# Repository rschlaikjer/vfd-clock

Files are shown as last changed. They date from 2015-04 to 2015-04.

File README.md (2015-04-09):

# VFD Clock

### Bedside clock with extended info

I'm a sucker for [old display technologies](https://github.com/rschlaikjer/ntp-nixie),
so on my arduino binge I built a bedside clock capable of displaying generic
information, with long line scrolling and whatnot. The design is fully PoE, so
the finished clock just needs one cable.

**In this repo:**
- Arduino code for the clock logic, handles fetching data from the server and VFD control.
- Eagle schematics for the clock control PCB
- Housing DXF for laser cut housing. The design is intended to be cut on a 6.7mm material.
- Server code manages actual information fetching (checking my unread mail, getting the price of bitcoin)

## Partlist
- Atmega 328P (along with 16MHz crystal, 2x 22pf caps)
- Silvertel A9700 PoE module
- ENC28J60 ethernet PHY
- RB1-125BHQ1A RJ45 jack with magnetics
- LM1117 3.3V regulator (for ENC28J60)
- VFD with serial interface (Here I'm using a Noritake CU20045SCPB-T31A)

## Pretty pictures

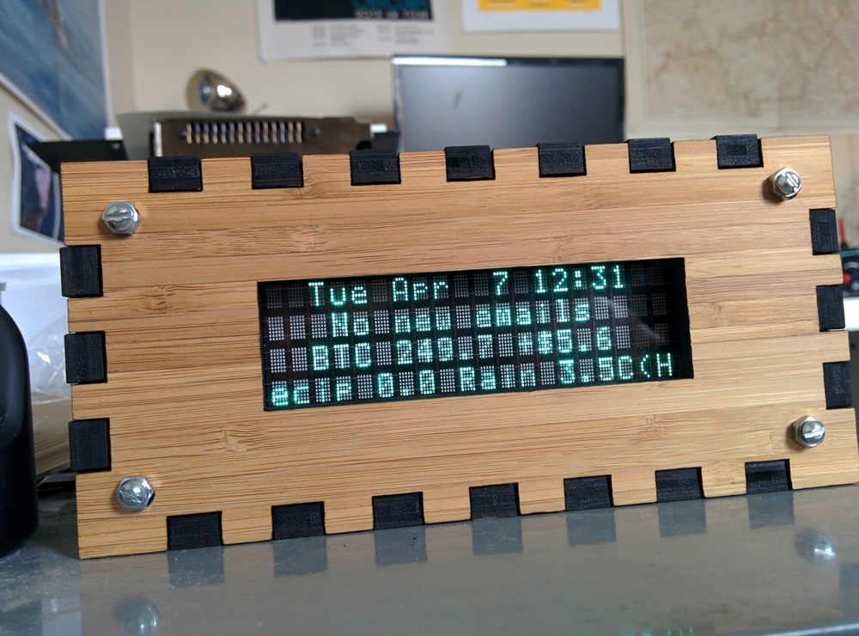
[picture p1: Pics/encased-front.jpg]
Front Front view

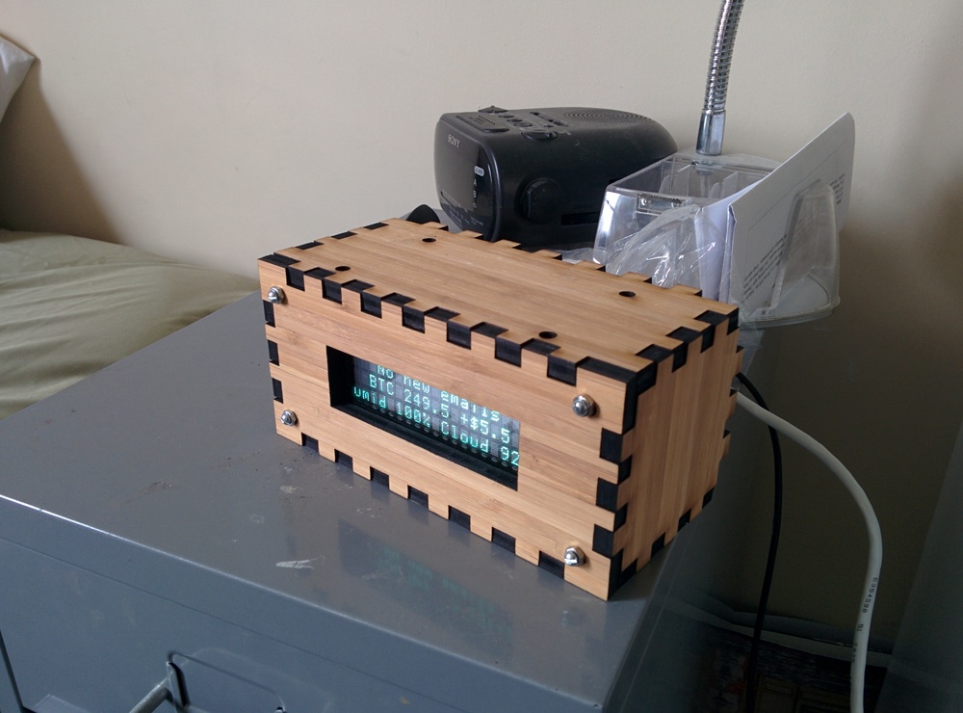
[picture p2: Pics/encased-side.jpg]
Side Side view

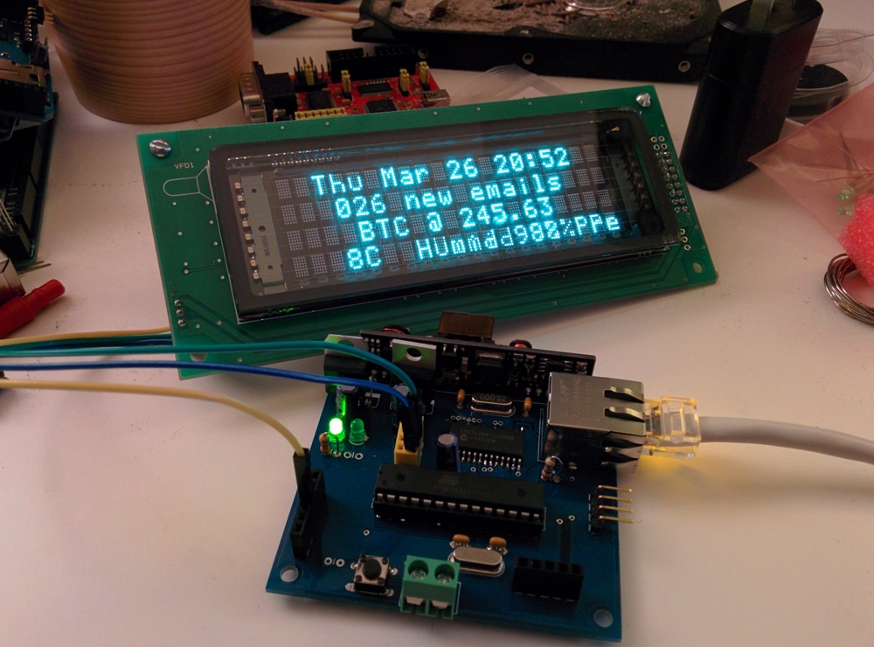
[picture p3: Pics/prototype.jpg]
Proto Initial testing


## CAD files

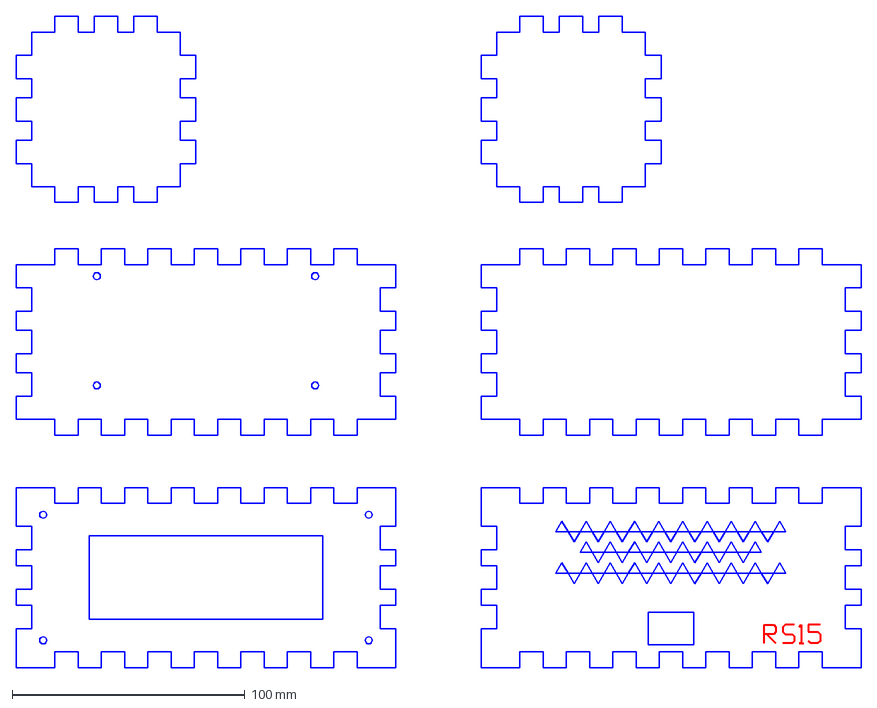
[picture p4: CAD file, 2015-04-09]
Housing/vfdclock.dxf
363.4 x 280.0 mm

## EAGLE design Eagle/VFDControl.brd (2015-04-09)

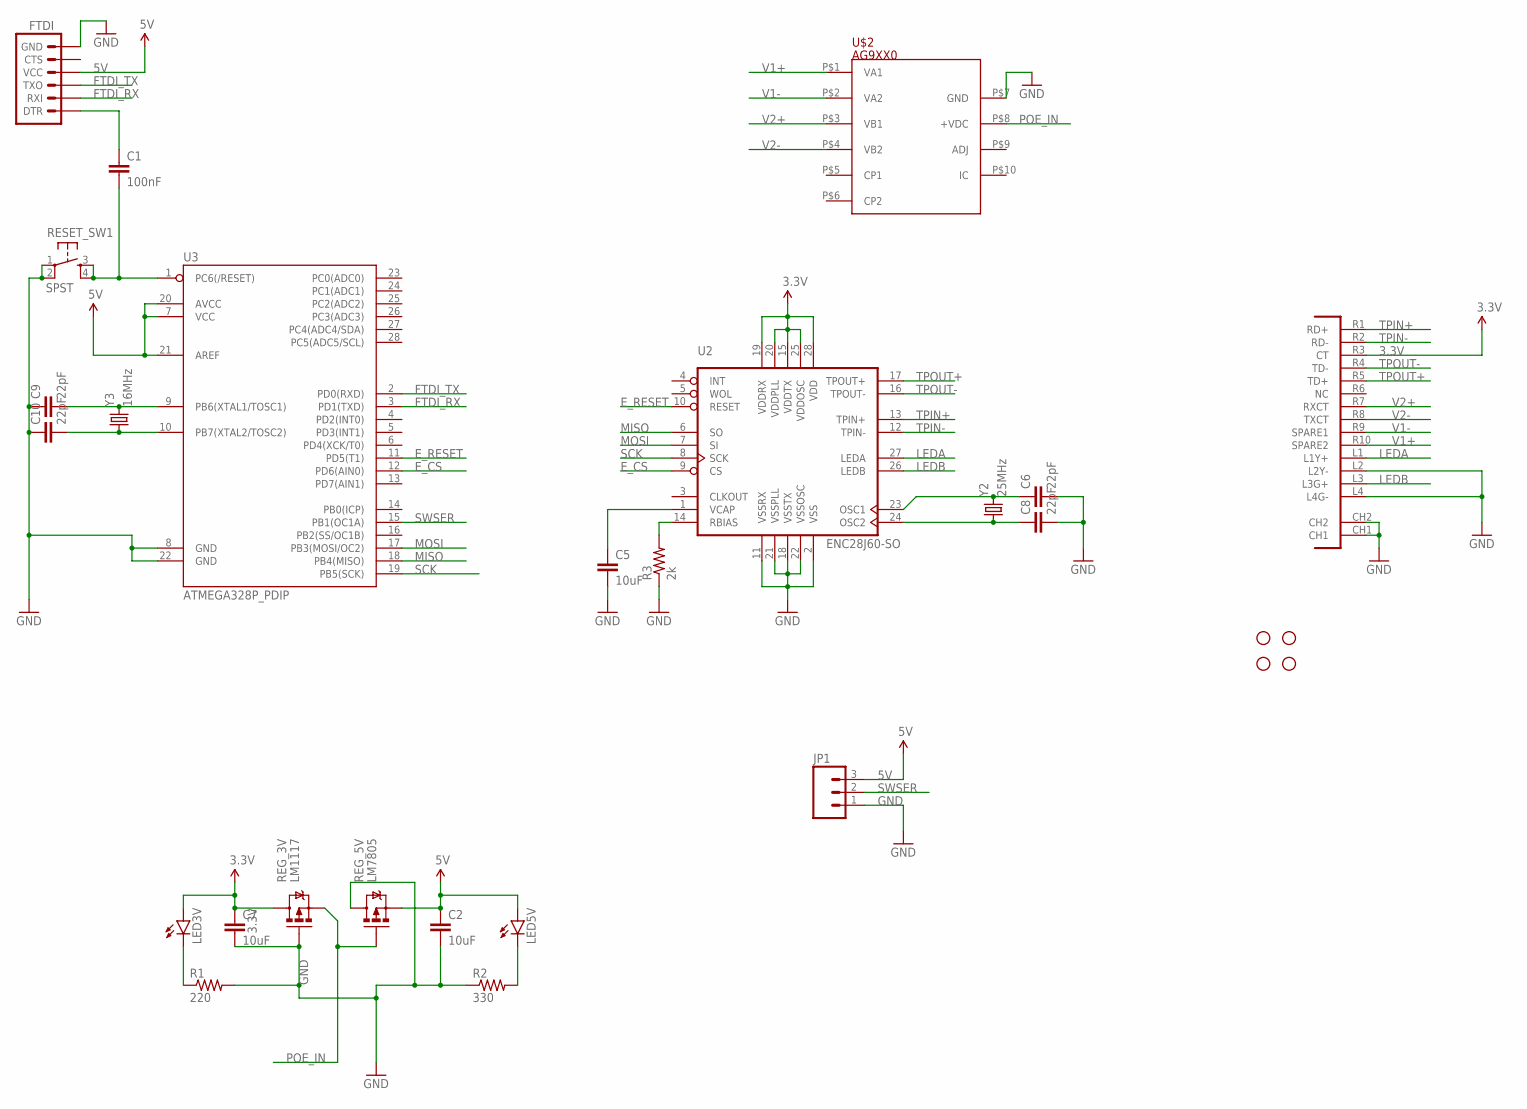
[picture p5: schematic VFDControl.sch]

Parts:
C1: 100nF; CAP-PTH-SMALL
C2, C5, C7: 10uF; CAP-PTH-SMALL
C6, C8, C9, C10: 22pF; CAP-PTH-SMALL
FTDI: ARDUINO_SERIAL_PROGRAMPTH; 1X06
JP1: M03PTH; 1X03
LED3V, LED5V: LED3MM
R1: 220; AXIAL-0.1
R2: 330; AXIAL-0.1
R3: 2k; AXIAL-0.1
REG_3V: LM1117; TO220V
REG_5V: LM7805; TO220V
RESET_SW1: SPST; TAC-SWITCH-PTH
STANDOFF1, STANDOFF2, STANDOFF3, STANDOFF4: STAND-OFF
U2: ENC28J60-SO; SO28W
U3: ATMEGA328P_PDIP; DIL28-3
U$2: AG9XX0; AG9000
U$3: POE-RJ45
Y2: 25MHz; HC49US
Y3: 16MHz; HC49US

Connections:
3.3V: C7.1, LED3V.A, REG_3V.2 (D), U2.15 (VDDTX), U2.19 (VDDRX), U2.20 (VDDPLL), U2.25 (VDDOSC), U2.28 (VDD), U$3.R3 (CT)
5V: C2.1, FTDI.4 (VCC), JP1.3, LED5V.A, REG_5V.3 (S), U3.7 (VCC), U3.20 (AVCC), U3.21 (AREF)
E_CS: U2.9 (CS), U3.12 (PD6(AIN0))
E_RESET: U2.10 (RESET), U3.11 (PD5(T1))
FTDI_RX: FTDI.2 (RXI), U3.3 (PD1(TXD))
FTDI_TX: FTDI.3 (TXO), U3.2 (PD0(RXD))
GND: C2.2, C5.2, C6.2, C7.2, C8.2, C9.1, C10.1, FTDI.6 (GND), JP1.1, R1.P$2 (2), R2.P$1 (1), R3.P$1 (1), REG_3V.1 (G), REG_5V.2 (D), RESET_SW1.1, RESET_SW1.2, U2.2 (VSS), U2.11 (VSSRX), U2.18 (VSSTX), U2.21 (VSSPLL), U2.22 (VSSOSC), U3.8 (GND), U3.22 (GND), U$2.P$7 (GND), U$3.CH1, U$3.CH2, U$3.L2 (L2Y-), U$3.L4 (L4G-)
LEDA: U2.27 (LEDA), U$3.L1 (L1Y+)
LEDB: U2.26 (LEDB), U$3.L3 (L3G+)
MISO: U2.6 (SO), U3.18 (PB4(MISO))
MOSI: U2.7 (SI), U3.17 (PB3(MOSI/OC2))
unnamed: LED3V.K (C), R1.P$1 (1)
unnamed: LED5V.K (C), R2.P$2 (2)
unnamed: R3.P$2 (2), U2.14 (RBIAS)
unnamed: C5.1, U2.1 (VCAP)
unnamed: C6.1, U2.23 (OSC1), Y2.2
unnamed: C8.1, U2.24 (OSC2), Y2.1
unnamed: C9.2, U3.9 (PB6(XTAL1/TOSC1)), Y3.2
unnamed: C10.2, U3.10 (PB7(XTAL2/TOSC2)), Y3.1
unnamed: C1.1, FTDI.1 (DTR)
POE_IN: REG_3V.3 (S), REG_5V.1 (G), U$2.P$8 (+VDC)
RESET: C1.2, RESET_SW1.3, RESET_SW1.4, U3.1 (PC6(/RESET))
SCK: U2.8 (SCK), U3.19 (PB5(SCK))
SWSER: JP1.2, U3.15 (PB1(OC1A))
TPIN+: U2.13 (TPIN+), U$3.R1 (RD+)
TPIN-: U2.12 (TPIN-), U$3.R2 (RD-)
TPOUT+: U2.17 (TPOUT+), U$3.R5 (TD+)
TPOUT-: U2.16 (TPOUT-), U$3.R4 (TD-)
V1+: U$2.P$1 (VA1), U$3.R10 (SPARE2)
V1-: U$2.P$2 (VA2), U$3.R9 (SPARE1)
V2+: U$2.P$3 (VB1), U$3.R7 (RXCT)
V2-: U$2.P$4 (VB2), U$3.R8 (TXCT)

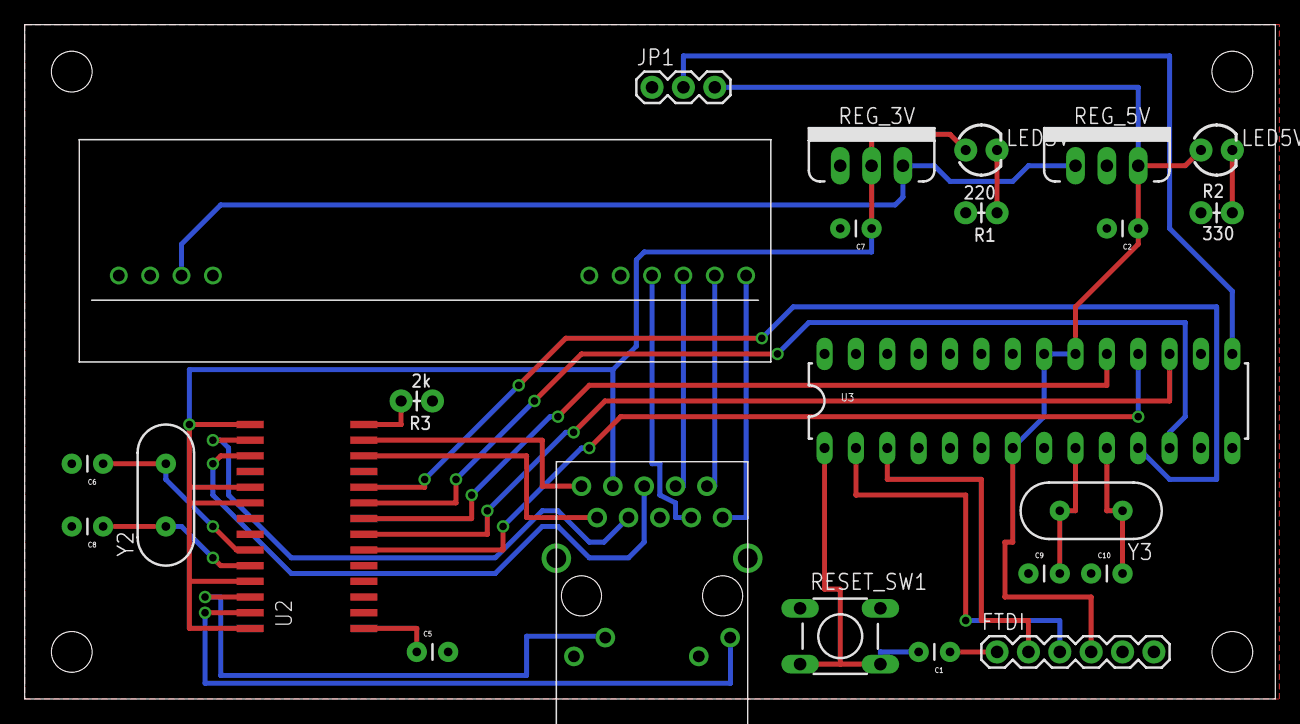
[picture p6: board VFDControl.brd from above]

Board: 2 copper layers, 101.3 x 54.6 mm, 28 parts (0 on the bottom side), 32 nets.

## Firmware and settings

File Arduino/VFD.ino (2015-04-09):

#include <SoftwareSerial.h>
#include <SPI.h>
#include <Wire.h>
#include <EtherCard.h>
#include <ArduinoJson.h>


// Ethernet
byte mac[] = {0xDE, 0xAD, 0xBE, 0xEF, 0xBA, 0xBE};
byte myip[] = { 192, 168, 0, 6 };
byte gwip[] = { 192, 168, 0, 1 };
byte Ethernet::buffer[512];
boolean OUTSTANDING_WWW_REQ = false;

// VFD
SoftwareSerial VFD(6,10); // RX, TX
#define VFD_LINES 4
#define VFD_COLS 20
#define VFD_COLMAX 64
char VFD_TEXT[VFD_LINES][VFD_COLMAX];
int VFD_SCROLL_INDEX[VFD_LINES];
int VFD_CUR_LINELEN[VFD_LINES];
short luminance = 0xFF;
short charset_control = 0x18;
#define VFD_TICK_MILLIS 125
#define DATA_CHECK_MILLIS 15000

// Function prototypes
void postTempData(short node_id, float temp, float pressure, float humidity);
void parseHTTPResponse();
void http_handle_resp(byte status, word off, word len);
void getInfoToShow();
void tick_vfd();

void setup() {
    // Start debug serial
    Serial.begin(9600);

    // Start serial for VFD
    VFD.begin(9600);
    int i, j;
    for (i = 0; i < VFD_LINES; i++){
        for (j=0; j < VFD_COLS; j++){
            if (i % 2){
                VFD_TEXT[i][j] = 0xD7;
            } else {
                VFD_TEXT[i][j] = '+';
            }
        }
        VFD_CUR_LINELEN[i] = VFD_COLS;
    }

    // Ethernet
    if (ether.begin(sizeof Ethernet::buffer, mac, 9) == 0){
        while (1);
    }

    ether.staticSetup(myip, gwip);
    ether.copyIp(ether.hisip, gwip);
}

/*
 * Main loop:
 * - Check for pending node transmissions
 * - Iterate over the node data we have stored, and see if any of it is dirty
 *     - If so, post it to the server
 * - Adjust relay based on response
 */
long long last_vfd_tick = 0;
long long last_data_fetch = 0;
void loop() {
    // Handle low-level ethernet data
    word len = ether.packetReceive();
    ether.packetLoop(len);

    if (millis() - last_vfd_tick > VFD_TICK_MILLIS){
        tick_vfd();
        last_vfd_tick = millis();
    }

    if (millis() - last_data_fetch > DATA_CHECK_MILLIS){
        getInfoToShow();
        last_data_fetch = millis();
    }
}

void getInfoToShow(){
    Serial.println("GET data...");
    ether.browseUrl(PSTR("/info"), "", PSTR("clock.rhye.org"), http_handle_resp);
    OUTSTANDING_WWW_REQ = 1;
    short retries = 0;
    while (OUTSTANDING_WWW_REQ && retries < 15){
        // Handle low-level ethernet data
        ether.packetLoop(ether.packetReceive());
        delay(100);
        retries++;
    }
}

void tick_vfd(){
    // Ensure flickerless mode
    VFD.write(0x1B);
    VFD.write(0x53);

    // Update luminance
    VFD.write(0x1B);
    VFD.write(0x4C);
    VFD.write(luminance);

    // Update charset
    VFD.write(charset_control);

    // Reset cursor to top left
    VFD.write(0x0C);

    // For each line, if the length is > the length of the VFD, increment the
    // scrolling tick index.
    // Print 20 characters of the line.
    int i, j, k;
    for (i=0; i < VFD_LINES; i++){
        // ESC (0x1B), 'H' (0x48), cursor position
        VFD.write(0x1B);
        VFD.write(0x48);
        VFD.write(i * 20);

        // CAN (clears the line)
        // CAN flickers a lot, use rewrite instead.
        //VFD.write(0x0F);

        if (VFD_CUR_LINELEN[i] > 20) {
            VFD_SCROLL_INDEX[i]++;
        }
        j = VFD_SCROLL_INDEX[i];
        for (k = 0; k < VFD_COLS && k < VFD_CUR_LINELEN[i]; k++){
            VFD.write(VFD_TEXT[i][j % VFD_CUR_LINELEN[i]]);
            j++;
        }
        for (; k < VFD_COLS; k++){
            VFD.write(" ");
        }
    }
}

void http_handle_resp(byte status, word off, word len){
    OUTSTANDING_WWW_REQ = 0;
    Serial.print("HTTP offset: ");
    Serial.println(off);

    Ethernet::buffer[off+len < 512 ? off+len : 511] = 0;
    for (; Ethernet::buffer[off]; off++){
        char c = Ethernet::buffer[off];
        if (c == '\n' || c == '\r'){
            off++;
            if (Ethernet::buffer[off] == '\n' || Ethernet::buffer[off] == '\r'){
                off++;
                if (Ethernet::buffer[off] == '\n' || Ethernet::buffer[off] == '\r'){
                    Serial.print("End of headers: ");
                    Serial.println(off);
                    off++;
                    break;
                }
            }
        }
    }
    Serial.println((char *)&Ethernet::buffer[off]);
    StaticJsonBuffer<512> jsonBuffer;

    JsonObject& root = jsonBuffer.parseObject((char *)&(Ethernet::buffer[off]));
    luminance = root["Luminance"];
    charset_control = root["Charset"];
    int i;
    for (i=0; i < VFD_LINES; i++){
        strncpy(VFD_TEXT[i], root["Line"][i], VFD_COLMAX);
        VFD_TEXT[i][63] = '\0';
        VFD_CUR_LINELEN[i] = strlen(VFD_TEXT[i]);
        VFD_SCROLL_INDEX[i] = 0;
        Serial.println(VFD_TEXT[i]);
    }
}

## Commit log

2015-04-09 Include sources
    [VFDControl.brd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]
2015-04-09 Add dxf for housing
    [vfdclock.dxf]

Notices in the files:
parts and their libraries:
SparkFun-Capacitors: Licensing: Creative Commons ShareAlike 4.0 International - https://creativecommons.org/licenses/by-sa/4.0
